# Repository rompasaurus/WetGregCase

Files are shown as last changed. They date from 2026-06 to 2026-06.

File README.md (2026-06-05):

# WetGregCase

A parametric, two-piece enclosure for the
[Dilder](https://github.com/rompasaurus) **Full PCB Rev 1**, generated by a
FreeCAD **PartDesign** macro.

> **Parametric, like `dilder_rev2_mk2`.** Every part is a PartDesign **Body**
> (Pad → Fillet → Thickness shell → pockets/pads) driven by a **`Parameters`
> spreadsheet**. Edit a cell and press **Ctrl+Shift+R**, or add/adjust fillets
> right on the feature tree in the GUI. All parts are single, watertight solids
> (clean B-rep — they slice without non-manifold errors).

- **Backplate** (Pico side) — the **board carrier**: wraps the board edge, the PCB
  **rests on top of a shelf** at its lower edge, with a **closed back panel** that
  closes off the +Z side (raised to clear the Pico).
- **Front cover** (screen side) — the screen lid below, built as a **constant-wall
  curved shell** so the aggressively curved front edge has no undercut gap. The
  screen sits recessed behind the front face (no clipping); the window is sized
  **inside the 4 M2 screw holes** so the frame fully covers them and the right-side
  8-pin connector. A round **5 mm boss** around the joystick hole leaves room for
  the solar-panel connector. The −X side is extended to wrap the screen edge.
- **Thumbpiece** — snap cap over the 5-way joystick (rev2-mk2 style).

The macro **imports the real KiCad STEP assembly**, aligned to the case — with the
unpopulated header pins **stripped** and the screen **shifted to meet the front
face** — so the fit is checked against actual geometry.

## Key facts

| | |
|---|---|
| Board | 97.8 × 42.0 × 1.6 mm, R5 corners |
| Screen face | meets screen top at Z = −11.4 |
| Backplate height | = USB-C connector (Z = +4.9) |
| Outer footprint | 105.4 × 46.6 mm (both plates, flush; −X extended for screen) |
| Overall height | **19.0 mm** (wall-thick shelled back clears the Pico) |
| Front curve | r = 6 mm — front **and** back edges (both shelled) |
| Closure | flush lap joint (tongue + relief) + PCB shelf + closed back |
| Controls | side USB-C opening · −Y power-switch slot · joystick thumbpiece |

## Layout

```
WetGregCase/
├─ freecad/
│  ├─ wetgreg_case.FCMacro   # parametric generator (edit PARAMS, re-run)
│  └─ WetGregCase.FCStd      # generated assembly
├─ exports/
│  ├─ WetGregCase_FrontCover.step
│  ├─ WetGregCase_BackPlate.step
│  └─ WetGregCase_Thumbpiece.step
├─ MODEL-SPEC.md             # full design spec, dimensions, open items
└─ README.md
```

## Run it

```bash
cd freecad && freecadcmd wetgreg_case.FCMacro   # headless regenerate
# or open the macro in the FreeCAD GUI and Execute
```

Then in the GUI: edit the **Parameters** spreadsheet and **Ctrl+Shift+R** to
recompute, or expand a Body in the tree to tweak any Pad/Fillet/Pocket. To add a
new fillet, select an edge and use PartDesign → Fillet.

> `freecad/wetgreg_case_partmode_backup.FCMacro` is the older non-parametric
> Part-workbench version, kept only as a reference.

See **[MODEL-SPEC.md](MODEL-SPEC.md)** for full dimensions and open items.

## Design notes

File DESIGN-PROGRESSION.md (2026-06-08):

# WetGregCase — Design Progression (manual FreeCAD walkthrough)

How to recreate this enclosure by hand in FreeCAD, step by step. The macro
(`freecad/wetgreg_case.FCMacro`) automates all of this from the `Parameters`
spreadsheet, but the steps below are what it does, in order.

**Coordinate frame (local):** `local = (KiCad_X − 46.70, KiCad_StepY + 88.0, Z)`
so the board sits at X 0..97.8, Y 0..42.012, with **Z = 0 at the PCB bottom**
face. +Z is the Pico/USB side (back), −Z is the screen/joystick side (front).

The case is a **clamshell**: a deep **front lid** (screen, Z −12.4 → 0) and a
deep **back cover** (Pico/USB, Z 0 → 8.5) that clips onto it.

---

## 0. New document
1. `File → New`. Save as `WetGregCase.FCStd`.

## 1. Import & align the Dilder PCB assembly (reference)
1. `File → Import` → `Dilder-PCB/Case Design/Dilder_PCB_FullAssembly.step`.
2. Select the imported part → **Edit → Placement** → Position `(−46.70, +88.0, 0)`.
   This lands the KiCad board into the local frame (board bottom at Z=0).
3. **Strip the unpopulated header pins:** delete the tall solid at the +Y edge
   (local X 8.4..28.7, Y 37..39.5, reaching Z +10.1) — those are empty holes.
4. **Keep the screen at its real STEP position (reality):** the imported screen's
   front face is at z=-8.64, which is ~1.36 mm behind the window-frame inner face
   (-10.0) — a genuine air gap, not a clip. `screen_cal`=0 leaves it there (the old
   build shoved it -1.36 mm onto the front floor, which made it clip the frame).
5. Keep this assembly visible, semi-transparent — it's the fit reference only.

## 2. Parameters spreadsheet
1. `Spreadsheet workbench → New sheet`, name it **`Parameters`**.
2. Add one row per dimension and **set an alias** on the value cell. Key ones:
   `board_w=96.8`, `board_h=42.012`, `wall=2.4`, `clear=0.3`, `ext_xmin=1.2`,
   `corner_r=7.7`, `screen_top=12.4`, `front_curve=6.0`, `back_above=8.5`,
   `back_curve=6.0`, `ledge_in=2.0`, `ledge_depth=10.0`, `lap=3.0`, `lap_fit=0.2`,
   `bead_proj=0.8`, `bead_h=1.2`, `snap_w=6.0`, `win_x0=11.6/x1=63.6/y0=7.1/y1=35.1`,
   `usb_*`, `sw_*`, `joy_*`, `thumb_*`, `bat_*`.
3. Drive every dimension below from these aliases (`Parameters.alias`) so editing
   a cell + **Ctrl+Shift+R** updates the model.

> Outer footprint corners (used below): X `−(ext+clear+wall)` .. `board_w+clear+wall`,
> Y `−(clear+wall)` .. `board_h+clear+wall`. Inner cavity = board + clear.

---

## 3. Front plate (screen lid) — PartDesign Body "FrontCover"
1. **New Body.** Sketch a rectangle on the XY plane at **Z = −12.4** covering the
   outer footprint (≈ 103.6 × 46.6). **Pad** it up to **Z = 0** (length `screen_top` = 12.4).
2. **Fillet** the 4 vertical edges → **7.7 mm** (rounded corners).
3. **Fillet** the front (−Z, bottom) perimeter edge → **6.0 mm** (the aggressive
   "looks-thin" curve).
4. **Thickness** (shell): select the open **+Z (top) face**, value **2.4 mm**,
   reversed/inward → a constant-wall curved shell, open at the top. *(Shelling
   after the fillet is what avoids the undercut gap the curve would otherwise make.)*
5. **PCB rib / ledge:** sketch a rounded **frame** (outer = wall inner; inner =
   2 mm further in, `ledge_in`) and **Pad it down** from Z=0 to the **front floor**
   (`ledge_depth` = `screen_top − wall` = 10.0). This is the lip the PCB rests on at
   Z=0, baked into the walls as a structural rib. Because the front wall curves
   inward below ≈−5.4, the straight rib outer ends up **inside** the curved wall,
   so the rib **merges with the curve** (no gap, no overhang, no poke-through) and
   meets the front face. Then Pocket a **screen-clearance box** (screen footprint
   +0.3, Z from the front floor up to `screen_back` (just past the real screen
   back) so the rib clears the screen on the −X edge.
6. **Screen window:** Pocket a rounded rectangle through the front frame, sized
   **inside the 4 M2 screw holes** so the frame covers them: X 11.6..63.6,
   Y 7.1..35.1 (1 mm shy of the screen PCB; X tucks the right-side 8-pin connector).
7. **Joystick boss:** add a **Ø20 cylinder**, **5 mm** tall, at (81.55, 21.30)
   from the front face inward — room for the solar-panel connector + thumbpiece.
8. **Battery / cable gap:** Pocket a blind notch at CN1 (X 41.5, −Y side) from the
   inside for routing battery cables. Its floor stops at **`bat_floor` (2.4 mm)
   above the front face** — i.e. just above the front floor — so the **front skin
   stays fully solid and printable** (no cut-through; the front is curved here, so
   the floor must clear the whole 2.4 mm front wall, not a thin slice). Start at the
   wall inner — **do not** cut the outer wall, and keep it below the window (Y < 7).
9. **Drill notches:** Pocket the rib away around the 2 mount holes closest to the
   Y axis (X 2.4, Y 9.0 and 33.4).
10. **Clip tongue + snap beads:** Pad a rounded frame ring up from Z=0 by
    `lap−lap_fit` (lap = 3 mm) at the inner wall, 0.2 mm clearance all round. Then
    add **discrete snap beads** (boxes) on the tongue's outer face — 2 per long
    wall + 1 on −X + **2 on +X flanking the USB-C port** (**7 total**) — each with a
    top lead-in chamfer. The bead projects
    `bead_proj` = 0.8 mm past the relief wall, so the thin tongue flexes ~0.6 mm and
    **clicks firmly** into the backplate recesses. The tongue is **continuous** all
    the way around — no relief cuts at the USB-C or switch — so the bead runs
    unbroken there for a stronger clasp. All inside the lap → **no added case
    thickness**. *(The 2.4 mm wall, +0.4 over the original 2.0, is what leaves a
    ~0.5 mm solid skin behind the deeper recess so the back wall isn't cut through.)*
11. **Joystick hole:** Pocket a **Ø12** cylinder through everything at (81.55, 21.30).

> **Sizing the +X length:** the case length is driven entirely by `board_w`
> (`OX1 = board_w + clear + wall`). To shorten the case, *reduce `board_w`* — never
> slab-cut the +X end, which would flat-chop the corner fillet and edge curve.
> `board_w` = 96.8 (1 mm under the KiCad nominal, matching the real board).

## 4. Back cover — PartDesign Body "BackPlate"
1. **New Body.** Rectangle on XY at **Z = 0** (outer footprint). **Pad** up to
   **Z = 8.5** (`back_above`).
2. **Fillet** vertical edges → 7.7 mm.
3. **Fillet** the **+Z (top) back edge** → 6.0 mm (same curve as the front).
4. **Thickness** (shell): open the **−Z (bottom) face**, 2.4 mm inward → curved
   closed back, walls, open toward the front. Houses the USB-C + Pico.
5. **Lap relief + snap recesses:** Pocket a rounded frame (inner wall, over the
   `lap` band from Z=0 up) to receive the front tongue. Then Pocket a **recess at
   each snap bead** in the relief wall — the relief wall stays solid between
   recesses, so the beads must flex past it and snap home.
6. **USB-C opening:** Pocket through the +X wall, Y 16.2..25.8, Z 0..5.2, with
   1 mm rounded corners.
7. **Power-switch slot:** Pocket through the −Y wall, X 47.5..53.5, Z 1.0..3.3.

## 5. Thumbpiece — PartDesign Body "Thumbpiece"
1. **New Body.** Additive **cylinder** Ø11 × 4.5 at (81.55, 21.30), front face.
2. **Subtractive sphere** R12 on the outer face → concave thumb dish.
3. **Subtractive box** 3.3 × 3.3 × 3.5 from the inner face → socket for the
   K1-1506SN-01 actuator.

## 6. Check
- Each Body should be a **single, closed (watertight) solid**.
- Front↔Back **interference = 0** when assembled (clip seats with 0.2 mm slip).
- Overall size ≈ **103.4 × 47.4 × 20.9 mm** (board_w 96.8; walls +0.4; curves intact).

---

## Why each measure
| Measure | Reason |
|---|---|
| translate (−46.70, +88, 0) | maps the KiCad STEP into the local frame |
| front-cover depth `screen_top` = 12.4 | screen standoff + 1 mm; screen rests just behind the window |
| shell (Thickness) after the fillet | curved wall with no undercut gap |
| ledge rib Z 0 → −10.0 (front floor) | PCB rests at Z=0; rib runs to the front floor, meshes with the curve, clears the screen |
| window inside the screw holes | frame fully covers the M2 holes + 8-pin connector |
| back cover Z 0 → 8.5 | clears the Pico (5.26) **and its micro-USB** under a wall-thick curved back |
| discrete snap beads inside the lap (0.55 mm interference) | front/back click together; no external features, no added thickness |
| ext_xmin = 1.2 | front = PCB + walls (not over-wide); clears the screen edge |

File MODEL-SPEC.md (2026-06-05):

# WetGregCase — Model Specification

A two-piece **slim** 3D-printed enclosure for the **Dilder Full PCB Rev 1**,
generated by `freecad/wetgreg_case.FCMacro`. The macro imports the real KiCad
STEP assembly (aligned, unpopulated header pins stripped, screen shifted to meet
the front face) and adds a snap-on joystick thumbpiece.

> Status: **v9 — parametric PartDesign rewrite.** Every part is a PartDesign Body
> (Pad → Fillet → Thickness shell → pockets/pads) driven by the **`Parameters`
> spreadsheet** (edit a cell + Ctrl+Shift+R, or add/adjust fillets on the feature
> tree). Both halves are curved constant-wall shells; all parts are single,
> watertight solids that slice cleanly. ~19.0 mm thick.
>
> Architecture (clamshell, seam at the PCB plane Z=0):
> * **FrontCover** = the screen lid (Z −11.4 → 0). Curved-shell front, screen
>   window, joystick boss/hole, battery-connector gap, and a **lip** the dilder
>   PCB rests on. All frame features are **rounded** (corners follow the wall
>   fillet — no corner overhang).
> * **BackPlate** = the deep cover (Z 0 → 7.5) that **clips onto the front lid**
>   and houses the **USB-C + Pico**; constant-wall curved shell with the **same
>   r6 edge curve as the front**, USB-C + switch openings.
> * Clip = flush lap (tongue on the front, relief in the back) + snap bead/groove.
>
> Feature tree: **FrontCover** = Pad → Fillet_Corners → Fillet_Front → Shell →
> Pad_Ledge → Cut_Window → Boss_Joy → BatteryGap → DrillNotches → Tongue + Bead →
> Cut_Joy. **BackPlate** = Pad → Fillet_Corners → Fillet_Back → Shell → Relief →
> Groove → USB → Switch. **Thumbpiece** = Disc → Dish → Socket.
>
> Closure: flush lap (tongue + relief, 0.2 mm slip) with a **snap bead + groove**
> running along the lap (bead on the front-cover tongue clicks into a groove in
> the backplate relief). The dilder PCB rests on a **thin side lip at Z=0** (USB
> cutout starts at Z=0 to match); the lip has a USB notch.

---

## 1. Orientation & coordinate frame

`local = (KiCad_X − 46.70, KiCad_StepY + 88.0, Z)` — **Z = 0 is the PCB bottom
face**; board X 0..97.8, Y 0..42.012.

| Side | Z | Contents | Case part |
|---|---|---|---|
| **Front** | **−Z** | WeAct screen + 5-way joystick | **Front cover** (screen lid) |
| **Back** | **+Z** | Pico W, USB-C, power switch | **Backplate** (board carrier) |

---

## 2. Real component geometry (from the STEP, local mm)

| Component | Side | X | Y | Z |
|---|---|---|---|---|
| WeAct screen | −Z | −0.4 … 71.6 | 6.1 … 36.1 | front shifted to **−11.4** |
| 5-way joystick | −Z | 75.7 … 87.4 | 16.2 … 26.4 | actuator to −10.1 |
| 8-pin connector | +Y | 8.4 … 28.7 | 37.0 … 39.5 | window stops 1 mm before (Y=36) |
| Pico W | +Z | 5.3 … 57.6 | 10.7 … 31.7 | 1.56 … 5.26 |
| USB-C | +Z | +X edge | 16.4 … 25.6 | 0.67 … **4.89** |
| Power switch | +Z | 47.2 … 53.9 | −Y edge | 1.06 … 3.07 |
| Header pins (empty) | +Z | 8.4 … 28.7 | 37 … 39.5 | **stripped** |

---

## 3. Architecture

```
                       aggressive front curve (r6)
  Z=-11.40  ╰─╮  screen window (stops before 8-pin) + joystick hole ╭─╯  = screen top
            FRONT COVER (screen lid) · 5 mm boss by joystick (solar conn.)
            −X side extended to wrap the screen edge + screw holes
  Z= -1.50 ═╪═════════════ FLUSH lap joint (shelf plane) ═══════════╪══  sides flush
  Z=  0.00       PCB rests ON TOP of the shelf  ───────────────────
            BACKPLATE (board carrier) — wraps board edge, open centre
            USB-C (+X) · switch slot (−Y)
  Z= +4.90  ╰──────────────────────────────────────────────────────╯  = USB-C height
```

### Backplate (board carrier, +Z)
- Wraps the board edge; only as tall as the USB-C connector (outer Z = +4.9).
- **Shelf under the board** (at the lower edge): the PCB **rests on top of it**.
  The shelf bridges the −X extension so it grips the board on all four sides.
- **Open centre** so it never touches a component (Pico exposed/accessible).
- **USB-C opening** (+X) · **power-switch slot** (−Y).

### Front cover (screen lid, −Z)
- Outer face **meets the screen top at Z = −11.4**; thin 1.2 mm front frame.
- **Screen window** inset by a 2.5 mm bezel so the frame **wraps the screen and
  covers the corner screw holes**; the +Y edge **stops 1 mm before the 8-pin
  connector** (pins hidden under the plate).
- **−X extended by 3 mm** so the wall wraps the screen's overhanging edge instead
  of clipping it.
- **5 mm-thick boss** around the joystick → room for the solar-panel connector and
  the thumbpiece.
- **Aggressive curve** (r = 6 mm) on the front outer edge.
- **Joystick hole** (Ø12) + flush lap tongue + snap nibs.

### Thumbpiece
- Snap cap over the K1-1506SN-01 actuator (rev2-mk2 style): Ø11 disc, dish,
  3.3 mm square socket. On the front.

---

## 4. Key dimensions

| Dimension | Value |
|---|---|
| Outer footprint (both plates, flush) | **105.40 × 46.61 mm** (−X extended 3 mm) |
| Overall height | **16.30 mm** (Z −11.40 → +4.90) |
| Screen face / backplate top | Z = −11.40 / +4.90 |
| Flush lap / PCB shelf top | Z = −1.50 / 0.00 |
| Wall / front frame | 2.0 / 1.2 mm |
| Joystick boss | 5.0 mm thick |
| Front curve | r = 6.0 mm |
| Bezel (screw-hole coverage) | 2.5 mm |
| PCB shelf | 1.6 mm grip, 1.5 mm thick |

All three printed parts verified as **valid, closed (watertight) solids**.
Imported assembly: 286 solids (1 header stripped, 99 screen sub-solids shifted).

---

## 5. Open items / confirm during validation

1. **Screen screw holes / bezel.** The 2.5 mm bezel covers holes within ~2.5 mm of
   the screen edge. If holes sit further in (or you want the exact active-glass
   window), give me the hole/active-area coordinates and I'll tighten it.
2. **−X extension (3 mm).** Sized to wrap the 0.4 mm screen overhang plus a full
   wall; adjust `ext_xmin` if you want it tighter/looser.
3. **5 mm joystick boss** spans X 71–93, Y 11–31. Tell me the solar-connector
   footprint if it needs a specific pocket rather than just thickness.
4. **Pico (5.26) vs backplate top (4.9):** Pico sits ~0.36 mm proud of the open
   backplate centre (exposed, no collision).
5. **Bezel overlaps the screen front** in the model (intended — the frame covers
   the border). The real screen sits flush behind it.
6. No bolt bosses (closure is snap + shelf). `import_assembly=False` for a
   case-only run; `explode_z` for an exploded view.

---

## 6. How to run

```bash
cd freecad && freecadcmd wetgreg_case.FCMacro     # headless regenerate
# or open the macro in the FreeCAD GUI → Execute
```

Outputs `freecad/WetGregCase.FCStd` and STEP files for the front cover, backplate
and thumbpiece in `exports/`.

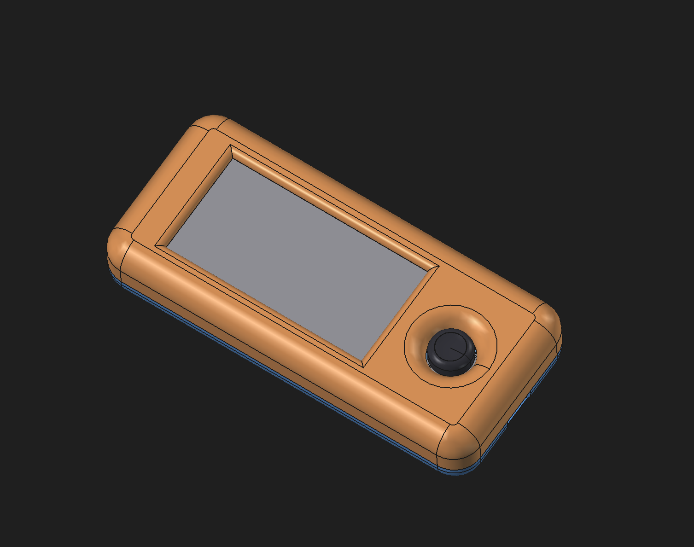
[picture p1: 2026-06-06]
WetGregCase FIrst Pass.png

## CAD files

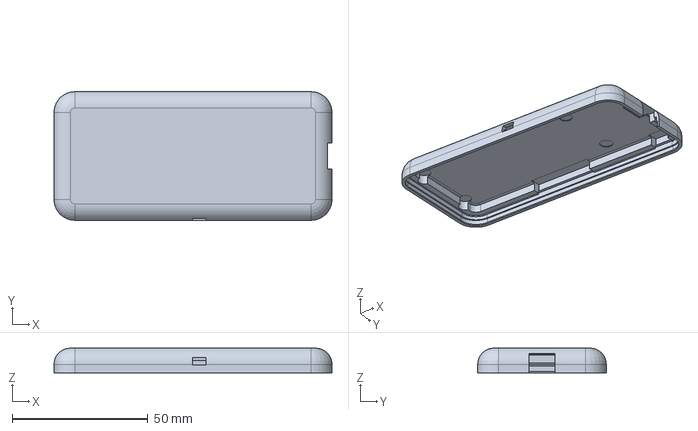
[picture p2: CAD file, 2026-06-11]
exports/WetGregCase_BackPlate.step
102.5 x 47.4 x 9.10 mm

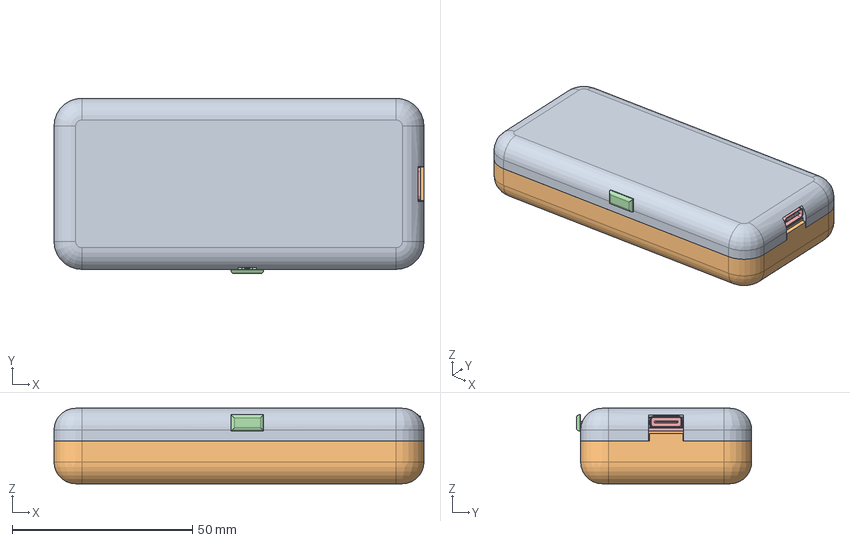
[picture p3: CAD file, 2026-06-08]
freecad/WetGregCase.FCStd
102.5 x 48.6 x 20.9 mm
BackPlate
FrontCover
Thumbpiece
SwitchSlider
Dilder_Assembly

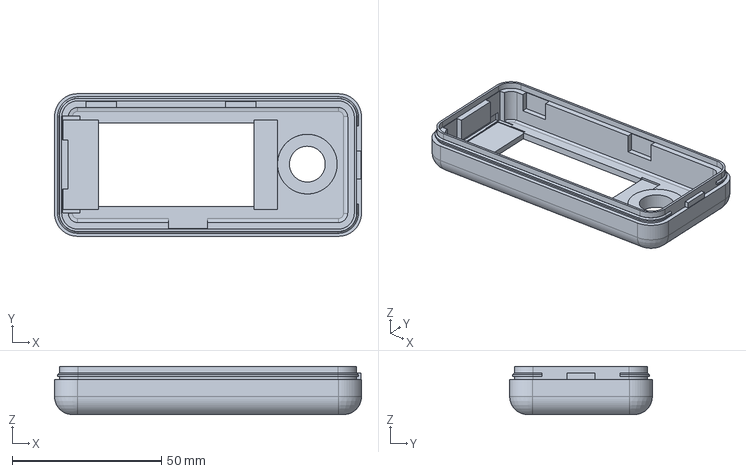
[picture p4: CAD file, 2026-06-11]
exports/WetGregCase_FrontCover.step
102.9 x 47.8 x 16.1 mm

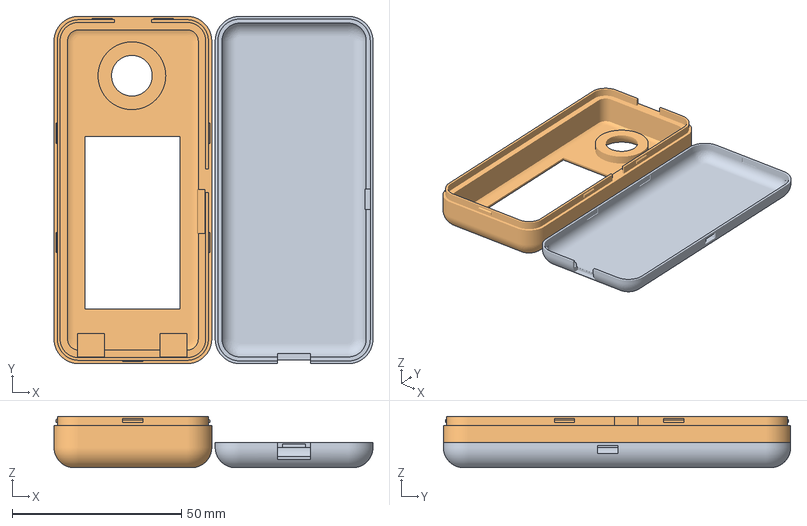
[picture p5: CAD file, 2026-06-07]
freecad/WetGregCase-almost htere2 front plated perfect need thiccer back.3mf
94.2 x 102.6 x 15.2 mm

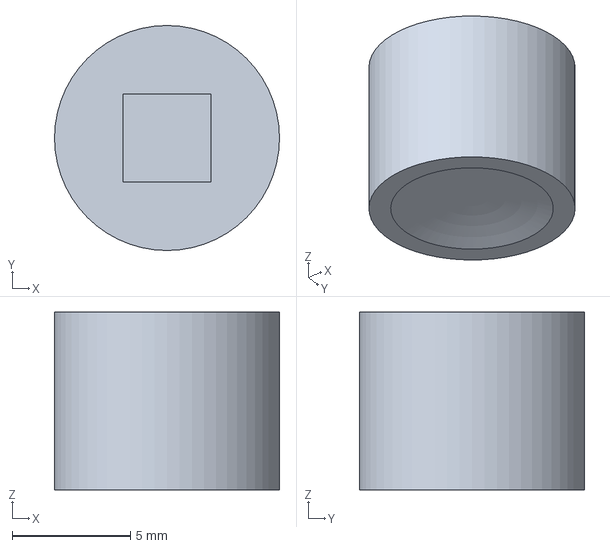
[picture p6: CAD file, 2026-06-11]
exports/WetGregCase_Thumbpiece.step
9.50 x 9.50 x 7.50 mm

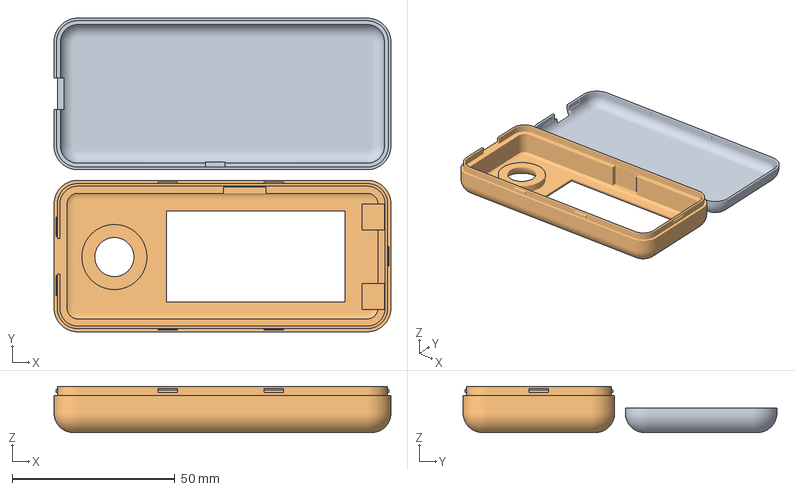
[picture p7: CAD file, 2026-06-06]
freecad/WetGregCase-almost htere.3mf
103.6 x 96.5 x 14.2 mm

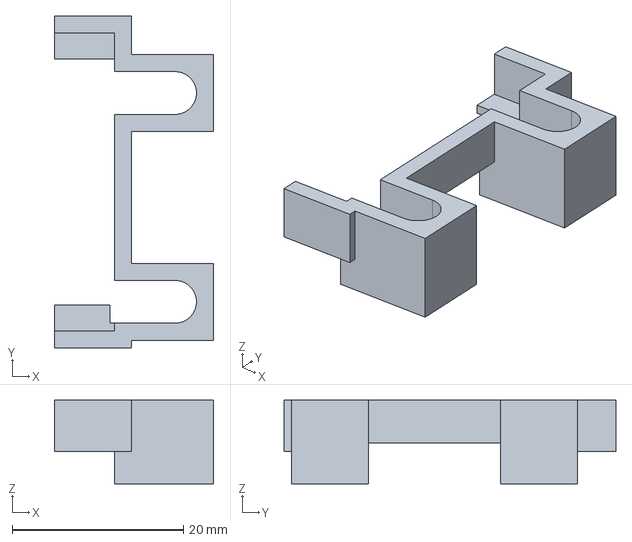
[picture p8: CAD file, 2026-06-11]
exports/WetGregCase_BatteryClipR.step
18.6 x 38.8 x 9.80 mm

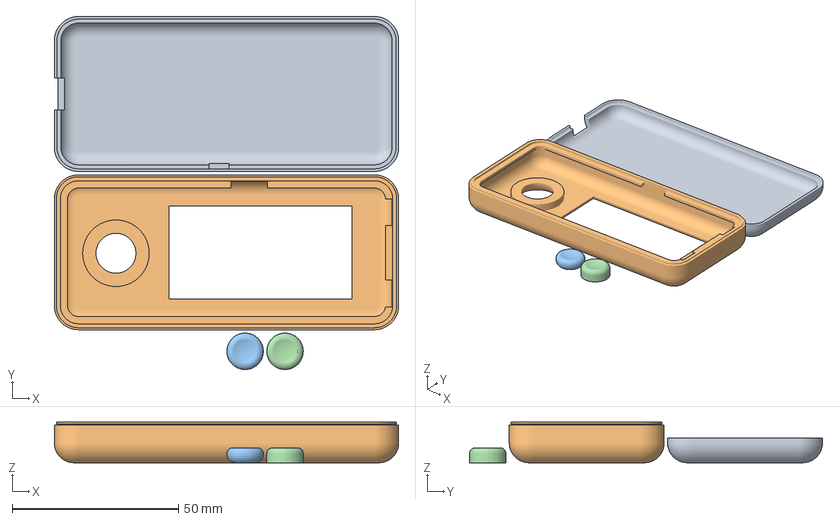
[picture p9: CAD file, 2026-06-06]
freecad/WetGregCase-Firs Attemptr.3mf
103.6 x 106.2 x 12.2 mm

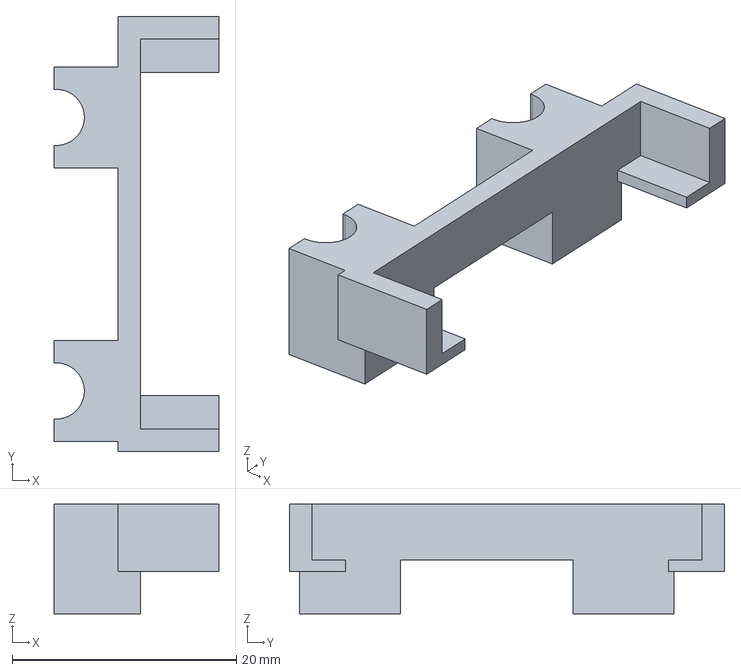
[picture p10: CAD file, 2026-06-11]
exports/WetGregCase_BatteryClipL.step
14.7 x 38.8 x 9.80 mm

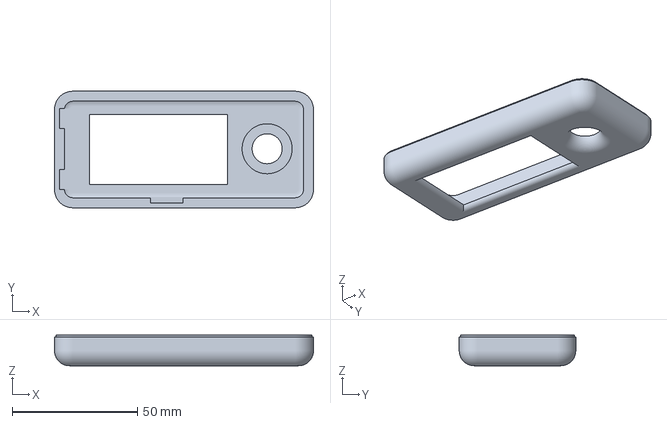
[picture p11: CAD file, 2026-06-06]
freecad/WetGregCase-FrontCoverPropper SHelf.3mf
103.6 x 46.6 x 12.2 mm

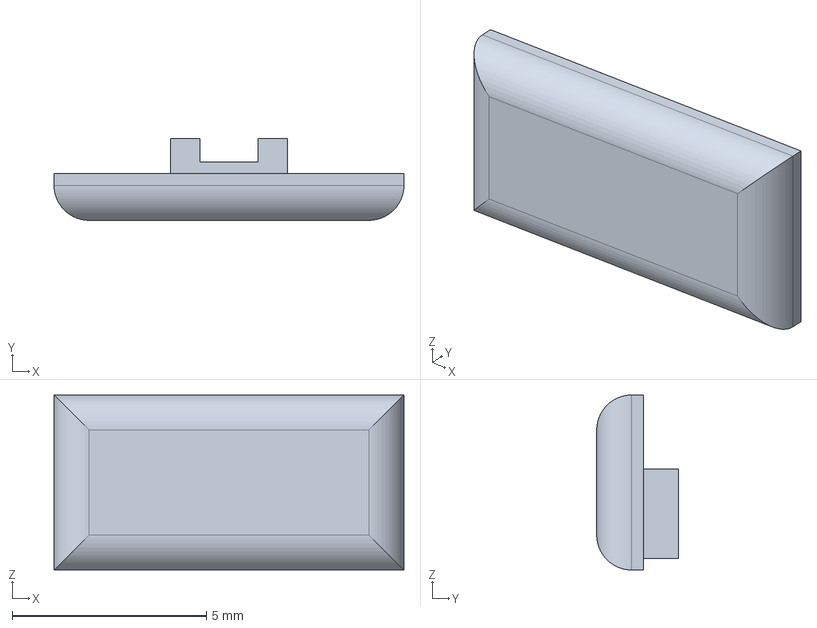
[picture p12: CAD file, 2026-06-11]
exports/WetGregCase_SwitchSlider.step
9.00 x 2.10 x 4.50 mm

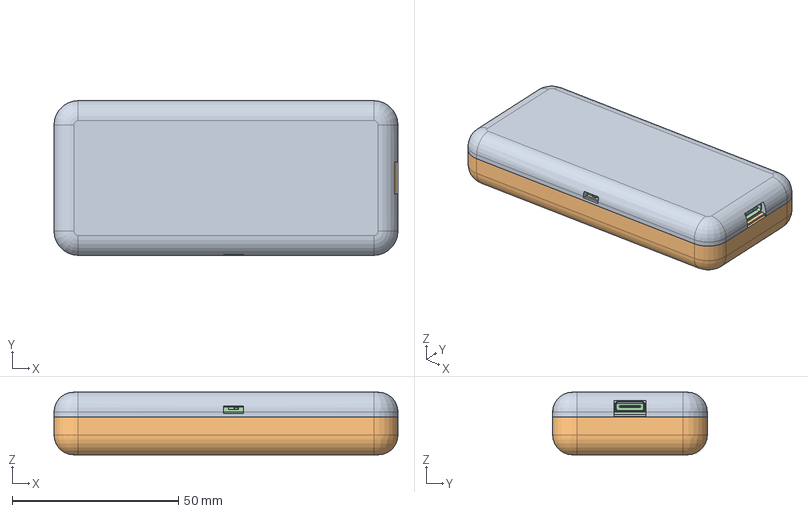
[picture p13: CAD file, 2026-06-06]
freecad/WetGregCase SOlid FIrst Pass.FCStd
103.6 x 46.6 x 18.9 mm
BackPlate
FrontCover
Thumbpiece
Dilder_Assembly

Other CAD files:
freecad/WetGregCase-BackPlate.3mf
freecad/WetGregCase-BatteryClipL.3mf
freecad/WetGregCase-BatteryClipR.3mf
freecad/WetGregCase-FrontCover.3mf
freecad/WetGregCase-SwitchSlider.3mf
freecad/WetGregCase-Thumbpiece.3mf

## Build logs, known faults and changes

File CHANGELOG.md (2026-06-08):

# WetGregCase — Revision History

Design revisions of the parametric FreeCAD enclosure, newest at the bottom.
Every part is driven by the `Parameters` spreadsheet in `freecad/wetgreg_case.FCMacro`.

| Rev | Change |
|---|---|
| init | Two-piece snap-fit case scaffold + GitHub repo |
| v1 | Flush lap joint, real KiCad STEP assembly import, joystick thumbpiece, switch slot |
| v2 | Slim case — screen+joystick on the front, thin USB-C-height backplate, curved front |
| v3 | Backplate as board carrier, screen wrap, joystick boss, window before pins |
| v4 | Closed back panel, curved shell (no undercut gap), recessed screen, round joystick boss |
| v5 | Screen window sized inside the 4 screw holes (fully covered) + back-edge curve |
| v6 | Screen window extended in Y to 1 mm shy of the screen-PCB edges |
| v7 | Narrow switch slot to actuator travel; tighten the USB-C opening |
| v8 | Slot the PCB shelf under the USB-C connector |
| **v9** | **Parametric PartDesign rewrite with a `Parameters` spreadsheet (like dilder mk2)** — clean B-rep, slices cleanly |
| v10 | Thin PCB side lip + snap bead/groove closure; narrow window −X edge |
| v11 | Fix mate z-fighting — all-around clearance on the lap tongue |
| v12 | Front plate becomes the tray (PCB on internal ledge); backplate = clip-on cap |
| v13 | Notch the front ledge around the 2 mount holes nearest the Y axis |
| v14 | Rounded frame features (no corner overhang); patch battery wall hole; narrower front |
| v15 | Clamshell flip — front = screen lid (lip), backplate = deep curved cover (USB+Pico) |
| v16 | Pad the PCB ledge down into a structural side rib |
| v17 | Extend battery gap into the curved front-bottom for cable routing |
| v18 | Keep the front floor solid under the battery gap (no cut-through) |
| v19 | Fix PCB rib overhang at the curve (straight-wall depth + 45° chamfer) |
| v20 | Rib meets the front face and meshes with the curve (no chamfer) + screen clearance |
| v21 | Raise front-cover depth +4 mm (PCB shelf 11.4 → 15.4) |
| v22 | Real snap-fit closure — discrete snap beads inside the lap (no added thickness) |
| v23 | Move +X snaps to flank the USB-C port (keep the port hole intact) |
| v24 | Fix snap recess depth (don't cut the back curve) + −X snap missing the extended wall |
| v25 | USB-C clearance gap in the front +X tongue (connector settles in) |
| v26 | Reduce front-cover depth back to the screen standoff (screen rests at the window) |
| v27 | +1 mm front-cover thickness; shave 2 mm off each end of the window's long edges (−4 mm); auto-export 3MF print meshes |
| v28 | Trim the +X end 1 mm past the USB-C (drops the +X snaps, keeps 5); cut a power-switch clearance gap in the front −Y tongue |
| v29 | **Undo the +X slab trim** (it flat-chopped the corner curve). Shorten by reducing `board_w` 97.8 → 96.8 so the whole case regenerates 1 mm shorter with all fillets/curves intact; restore the 2 +X snaps flanking the USB-C |
| v30 | Deepen the backplate 1 mm (`back_above` 7.5 → 8.5) so it closes flush over the Pico's micro-USB |
| v31 | Stronger clasp: drop the front-tongue relief cuts at the USB-C & switch (`Cut_FC_USB`/`Cut_FC_Switch`) so the bead runs unbroken; +0.4 mm bead projection (0.4 → 0.8); +0.4 mm walls all around (`wall` 2.0 → 2.4, `corner_r` → 7.7) to keep a solid recess skin and mate smoothly; +0.2 mm USB-C opening depth (`usb_z1` 5.0 → 5.2) |
| v32 | Extend the window's Y-axis edge 1 mm toward the Y axis (`win_x0` 12.6 → 11.6) |
| v33 | Extend the USB-C opening depth another 0.4 mm (`usb_z1` 5.2 → 5.6) |
| v34 | Extend the USB-C opening depth another 0.4 mm (`usb_z1` 5.6 → 6.0; ~at the inner ceiling 6.1) |
| v35 | Carve the USB-C slot up into the curved top cap (`usb_z1` 6.0 → 7.5) so the connector clears the curvature; ~1 mm cap roof remains, curve intact off the USB window |
| v36 | Run the USB-C slot clean through the curved cap to the back face (`usb_z1` 7.5 → 9.0 ≥ cap top) — open-topped notch, no curve overhang; cap intact outside the USB window |
| v37 | Start the USB-C cut `back_curve` (6 mm) further inboard so it also removes the top cap's inward lean over the USB window (the rounded edge curves toward −X near the top); cap intact off the USB window |
| v38 | Pull the USB-C cut back from the base (`usb_z1` 9.0 → 7.0): no longer cuts through the back face, leaves a ~1.5 mm solid cap roof (still clears the connector ~4.9) |
| v39 | Front-cover outer lip at the USB notch (`Lip_FC_USB`, `usb_lip_h`=2.1): fills the lower part of the backplate's USB cutout flush with the outer surface, covering the bead/seam; +0.4 mm back-cover depth (`back_above` 8.5 → 8.9) so the Pico clears the shell |
| v40 | Raise the power-switch slot 1 mm (`sw_z0` 1.0 → 2.0, `sw_z1` 3.3 → 4.3); confirmed it cuts clean through the −Y wall |
| v41 | Reduce the USB-C cutout depth 0.6 mm (`usb_z1` 7.0 → 6.4); thicker ~2.5 mm cap roof, still clears the connector |
| v55 | Back cover +1 mm (`back_above` 8.1 → 9.1, overall 20.93). Cut the +Y (top) shelf away at the middle for the accelerometer so the board lays flat, and gap the shelf at the +X/−Y corner (by the USB-C) for the LEDs (both start at the wall inner — no side holes) |
| v54 | Fix the back shelf's switch/battery gap cutting a **hole in the −Y side wall** (the gap started outside the wall) — gaps now start at the wall inner and only remove the inner shelf. Reduce the back cover 2 mm (`back_above` 10.1 → 8.1): the Pico is modelled as a solid 3.7 mm block but the real Pico is mostly thin PCB, so the dead space above it is removed (overall 21.93 → 19.93) |
| v53 | (a) Front: carve 1 mm more into the inner −X wall at the screen edge (`scr_carve_in`; leaves 1.2 mm wall, no pop-through). (b) Bead +1 mm taller (`bead_h` 1.2 → 2.2, centred so the USB-C still clears the tongue; snap still seats). (c) **Back perimeter support shelf** (`Pad_BP_Shelf`) clamping the board's outer edge between the front rib and the shelf, with M2 standoff notches, USB-C/switch/battery gaps, and an open centre clearing the Pico/accel/LEDs/caps |
| v52 | Trim the back cover to its minimum closed depth (`back_above` 10.2 → 10.1). The Pico (7.36) is the tallest +Z part — 0.37 mm above the USB-C (6.99) — so the closed back is set by the Pico, not the USB-C; ceiling now clears the Pico by 0.35 mm |
| v51 | Deepen the front cover for the real screen stack: measured **13 mm** top-of-screen to PCB-backside (STEP model had it ~2.9 mm too close). `screen_top` 8.94 → 11.83, `screen_cal` 0 → −2.89 (shift screen out to reality), `ledge_depth` → 11.53. Screen now sits just behind the window, no poke; stack verified 13.00 mm. Overall 19.14 → 22.03 |
| v50 | Fix the M2 drill-notch z: it used the pre-raise rib bottom (`-ld`), which after the board raise sliced through the front wall → holes at the screen top. Now tracks the raised rib (`pcb_rest_z - ld`); front face solid again |
| v49 | Fix two v48 regressions: board now sits **exactly flush** with the bead top (`board_rest_z` 2.13 → 2.10 = bead top); and **restore the USB-C + Pico** to the reference assembly — the header-strip threshold (ZMax>6) now rises with `board_rest_z`, so the raised Pico/USB are no longer deleted as if they were header pins |
| v48 | **Board now rests ON the bead** (`board_rest_z` 0.63 → 2.13): the board bottom sits ~at the bead top, lifting the USB-C base (2.80) clear of the tongue top (2.8). So the **USB tongue relief is removed entirely** (`Cut_FC_USB` gone) — the bead/tongue fully connect under the connector — and the **lip meets the bead top** (`usb_lip_h` → 2.10). Back deepened (`back_above` → 10.2) so the now-higher Pico clears; front thinner (`screen_top` → 8.91); `usb_z1` → 7.2 for the raised connector. Overall 19.31 → 19.11 |
| v47 | **Raise the board so the PCB top is flush with the bead top** (new `board_rest_z`=0.63; bead restored to the lap centre). Lifts the USB-C/switch into the backplate (accessible) and lets the front USB lip grow (`usb_lip_h` 0.67 → 1.3). Front thinner (`screen_top` → 10.41; overall 19.94 → 19.31); Pico still clears (back unchanged). Slider tab thinner + rounded (more flush to the side) and tracks the raised switch |
| v46 | **Slide-switch (MSK12C02) slider — v1.** Enlarge the −Y slot to a slider window (`sw_*`/`sld_*` params) exposing the actuator; add a printed `SwitchSlider` part (thumb tab + neck + knob grip pocket) that rides the slot. Valid solid, fits with clearance. Grip + full case-rail capture need the real knob width/travel/protrusion (assumed 1.2/1.5/0.6 mm) |
| v45 | Lower the snap bead so its top is flush with the PCB top (`bead_z` = board_t − bead_h; `board_t` 1.6 → 1.47 real). USB tongue relief kept minimal — raising the board to clear it would push the Pico into the back cover (thicker), which conflicts with the connector sitting below the PCB top |
| v44 | Bring the −X short side in 0.9 mm (`ext_xmin` 1.2 → 0.3) so the wall clears the screen overhang (−0.394) by 0.2 mm; keep the screen-clearance pocket from breaching the tightened wall. Restore the USB lip to meet the connector (`usb_lip_h` 0.5 → 0.67) |
| v43 | **Front cover 1.36 mm thinner** to match reality: real screen sits 8.64 mm from the board, so `screen_top` 12.4 → 11.04 (`ledge_depth` → 8.64). Window inner now meets the screen so the board seats on the shelf; overall height 21.3 → 19.94 |
| v42 | **Calibrate the reference assembly to reality.** Keep the screen at its authoritative STEP position (`screen_cal`=0; was shoved −1.36 mm onto the case front floor) → it now sits ~1.36 mm behind the window as in reality. Extend the rib's screen-clearance to the real screen back (`screen_back`). Fix the USB-C colliding with the front cover: lower the lip below the connector (`usb_lip_h` 2.1 → 0.5) and re-add a narrow tongue relief at the USB window (lip + flanking beads kept) |

## Current key dimensions (v55)

| | |
|---|---|
| Outer footprint | 102.5 × 47.4 mm (−X brought in to clear the screen +0.2) |
| Overall height | 20.93 mm |
| Front-cover depth | `screen_top` = 11.83 mm (real screen 8.64 − board_rest_z + wall) |
| Backplate depth | `back_above` = 9.1 mm (USB-C + Pico; clears micro-USB + Pico-to-shell) |
| Wall / curves | 2.4 mm walls · r7.7 corners · r6 front **and** back edge curves |
| Screen window | X 11.6–63.6, Y 7.1–35.1 (inside the screw holes; long edges shaved) |
| Closure | flush lap + discrete snap beads (2/long wall + 1 −X + 2 +X flanking the USB-C = 7), 0.8 mm projection, tongue continuous at the USB/switch |
| Controls | side USB-C opening · −Y switch slot · joystick boss + thumbpiece |

## Outputs (regenerated by the macro)
- `freecad/WetGregCase.FCStd` — full assembly + Parameters spreadsheet
- `exports/WetGregCase_{FrontCover,BackPlate,Thumbpiece}.step`
- `freecad/WetGregCase-{FrontCover,BackPlate,Thumbpiece,SwitchSlider}.3mf` — print-ready meshes
- `exports/WetGregCase_SwitchSlider.step`

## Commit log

2026-06-05 Initial WetGregCase: parametric 2-piece snap-fit case for Dilder PCB
    Two-piece enclosure generated by a FreeCAD macro:
    - Back plate tray with inward lip the PCB rests on
    - Front plate snaps around it, screen window for WeAct e-ink
    - 11.4mm screen clearance above PCB top, +2mm back allowance
    - Embeds full KiCad layout (screen, battery, joystick, Pico W, USB-C, switch)
    - Validated as watertight solids; STEP exports included
    [WetGregCase.FCStd, WetGregCase_BackPlate.step, WetGregCase_FrontPlate.step]
2026-06-05 v1: flush lap joint, real STEP assembly import, joystick thumbpiece, switch slot
    - Import the real Dilder_PCB_FullAssembly.step (287 solids) aligned to the
    case frame; replaces crude primitive component boxes
    - Fix Y-mirror: case now built in the true STEP frame (translate -46.70,+88,0),
    so the power switch lands on the correct (-Y) wall
    - Flush lap joint: both plates share one outer footprint (102.4x46.6) with an
    interlocking tongue/relief + 6 internal snap detents (sides flush, no overhang)
    - Add joystick thumbpiece (K1-1506SN-01, rev2-mk2 style) + Oe12 hole on back
    - Power-switch slot on -Y wall for external toggling
    - Back cavity 10.5mm to clear real back components (joystick/conne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
    [WetGregCase.FCStd, WetGregCase_BackPlate.step, WetGregCase_FrontPlate.step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]
2026-06-05 v2: slim case — screen+joystick front, thin USB-C-height backplate, curved front
    - Correct orientation: screen and joystick are on the SAME side (-Z); screen
    window + joystick hole/thumbpiece now both on the front cover
    - Front cover outer face meets the screen top (Z=-11.4); thin 1.2mm frame
    - Thin backplate on the Pico side, only as tall as the USB-C connector (Z=4.9),
    a perimeter frame with a small shelf the PCB rests on, open centre (won't
    touch components)
    - Aggressive curved front edge (r6) so the case reads thinner than it is
    - Import: strip unpopulated header pins, shift screen (99 solids) to meet face
    - Overall height 25.1 -> 16.3mm; all parts valid + watertight
    Co-Authored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
    [WetGregCase.FCStd, WetGregCase_BackPlate.step, WetGregCase_FrontCover.step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]
2026-06-05 v3: flip to board-carrier backplate, screen wrap, joystick boss, window-before-pins
    - Flip architecture per feedback: BACKPLATE is now the board carrier (wraps the
    board edge; PCB rests ON TOP of a shelf at its lower edge). FRONT COVER is the
    screen lid below. Lap mates on the correct edge.
    - Window now stops 1mm before the 8-pin connector (Y=36) so those pins are hidden
    under the front plate
    - Extend case -X by 3mm so the front wraps the screen's overhanging edge (was
    clipping through the wall); bezel 2.5mm to cover the screen's corner screw holes
    (shelf bridges the extension to keep gripping the board on all sides)
    - Add 5mm-thick boss by the joystick to leave room for the solar-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
    [WetGregCase.FCStd, WetGregCase_BackPlate.step, WetGregCase_FrontCover.step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]
2026-06-05 v4: closed back panel, curved shell (no gap), recessed screen, round joystick boss
    - Front cover now a constant-thickness curved SHELL (makeThickness): the r6
    front curve no longer undercuts the wall -> fixes the weird empty-space gap
    - Recess the screen behind the front inner face so the frame no longer clips
    the screen/screw holes (overlap 307 -> 0.9 mm^3)
    - Backplate closes off the +Z side with a closed back panel (raised to clear
    the Pico, 5.26mm); verified 4867mm^2 closed top
    - Joystick fill is now a round 5mm boss right around the hole, not a square block
    - All parts valid + watertight; height 16.3 -> 18.4mm (closed back)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
    [WetGregCase.FCStd, WetGregCase_BackPlate.step, WetGregCase_FrontCover.step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]
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2026-06-05 v7: narrow switch slot to actuator travel + tighten USB-C opening
    - Switch slot 9.7 -> 6.0mm (X 47.5..53.5), Z 0.4..3.5 -> 1.0..3.3: just enough
    for the slide actuator to move (switch body is 47.2..53.9)
    - USB-C opening tightened to hug the connector (Y 9.7mm vs body 9.1, Z 0.5..5.0
    vs body 0.67..4.89) with 1mm rounded corners for the port shape
    - All parts valid + watertight
    [WetGregCase.FCStd, WetGregCase_BackPlate.step, WetGregCase_FrontCover.step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]
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2026-06-05 v10: thin PCB side lip + snap bead/groove closure + narrow window -X edge
    - Replace the thick bottom shelf with a thin side LIP at Z=0 (board bottom rests
    on it); drop USB cutout bottom to Z=0 so the lip starts where the USB cutout
    ends (closest to origin); lip keeps a USB notch. PCB no longer shifted.
    - Add a snap BEAD on the front-cover tongue + matching GROOVE in the backplate
    relief -> clicks the two halves closed along the lap (seated overlap 0;
    interference only during insertion)
    - Bring the screen window -X edge in 5mm (win_x0 5.6 -> 10.6)
    - Verified: lip on side walls (open centre), PCB rests on it, all three parts
    single watertight solids; bead/groove/lip present in the fe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
    [WetGregCase.FCStd, WetGregCase_BackPlate.step, WetGregCase_FrontCover.step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]
2026-06-05 v11: fix mate z-fighting — give the lap tongue all-around clearance
    The 'weird planes clipping through the back' were coincident faces at the mate:
    the front-cover tongue shared planes with the backplate lip (both at O_IN) and
    the relief walls (overlapping in Z), so FreeCAD z-fought them when both parts
    were shown.
    - Inset the tongue inner by lap_fit and shorten it below the relief top, so it
    sits inside the relief with 0.2mm clearance on inner/outer/top (no shared
    planes). Snap bead still engages (interference only during insertion).
    - Verified: FC<->BP solid overlap 0; the only touching face is the outer seam
    (the intended flush closing contact). All parts single watertight solids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
    [WetGregCase.FCStd, WetGregCase_BackPlate.step, WetGregCase_FrontCover.step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]
2026-06-05 v12: front plate becomes the tray (PCB on internal ledge); backplate is a clip-on cap
    Per feedback: the dilder PCB now rests INSIDE the front plate.
    - Move the seam up above the Pico (Z=5.5) so the FRONT plate is the full tray
    holding the screen + PCB; the PCB rests on an internal LEDGE where the side
    walls come in 2mm at Z=0 (Pad_FC_Ledge)
    - Move the USB/switch cutouts into the front plate; add a battery-connector gap
    at CN1 (-Y side) through the ledge/wall
    - Backplate is now a thin CAP that clips around the front plate flush (lap relief
    + snap groove + closed-top skin); removed the old shelf/shell
    - Verified: all single watertight solids, FC<->BP overlap 0, PCB rests on ledge,
    ba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
    [WetGregCase-FrontCover.3mf, WetGregCase-Thumbpiece.3mf, WetGregCase.FCStd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]
2026-06-05 v13: notch the front-plate ledge around the 2 mount holes closest to the Y axis
    - Cut ledge notches at the two e-ink M2 mount holes nearest the Y axis
    (local x=2.4: (2.4,9.0) and (2.4,33.4)) so the ledge doesn't cover them;
    no through-hole, just the ledge relieved. Verified gaps at the holes, ledge
    intact between them; all parts single watertight solids.
    [WetGregCase.FCStd, WetGregCase_BackPlate.step, WetGregCase_FrontCover.step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]
2026-06-05 v14: rounded frame features (no corner overhang), patch battery wall hole, narrower front
    - frame_sketch now builds ROUNDED rectangles (corners follow the case fillet) so
    the ledge/tongue/bead no longer poke out past the rounded walls -> fixes the
    'rectangular overhang at the mate' and 'lip clipping out at the curved corners'
    - battery-connector gap now relieves only the ledge/interior, not the outer wall
    (cut starts at the wall inner) -> patched the side-wall hole
    - reduce -X extension (ext_xmin 3.0 -> 0.6): front plate = PCB width + walls
    (103.0mm, was 105.4)
    - verified: all single watertight solids, wall patched, ledge relieved, no overhang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
    [WetGregCase.FCStd, WetGregCase_BackPlate.step, WetGregCase_FrontCover.step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]
2026-06-05 v15: clamshell flip — front=screen lid (lip), backplate=deep curved cover (USB+Pico)
    - Seam moved to Z=0 (PCB plane). FRONT plate is now the screen lid (-11.4..0)
    with the PCB lip on top; BACKPLATE is the deep cover (0..7.5) that clips on and
    houses the USB-C + Pico, with the SAME r6 curved closed back as the front.
    - Moved USB-C + switch cutouts into the backplate; battery gap stays on the front
    (screen side), relieving only the ledge (not the outer wall).
    - All frame features (ledge/tongue/bead/relief/groove) are rounded -> no corner
    overhang at the mate or curved corners.
    - ext_xmin tuned to 1.2 (front = PCB + walls, 103.6mm); residual screen-corner
    overlap is the screen model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
    [WetGregCase.FCStd, WetGregCase_BackPlate.step, WetGregCase_FrontCover.step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]
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2026-06-06 v18: fix battery gap cutting through the front; keep the front floor solid
    - The front is CURVED at the battery gap (-Y edge), so a thin skin measured from
    the flat -11.4 plane wasn't actually solid and broke through.
    - Raise bat_floor 0.8 -> 2.4 so the gap floor sits ABOVE the whole 2mm front wall:
    the front skin is now fully solid/printable across the battery area (verified
    solid material below the gap at every sampled point, no cut-through). Cable space
    remains from ~-9.0 up (upper curve + rib).
    [WetGregCase.FCStd, WetGregCase_BackPlate.step, WetGregCase_FrontCover.step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]
2026-06-06 v19: fix PCB rib overhang at the curve — keep it on the straight wall + 45deg chamfer
    - The rib (at the straight wall position) detached where the front wall curves
    inward below Z=-5.4, leaving a hanging overhang.
    - Cap ledge_depth at 5.4 (= screen_top - front_curve) so the rib bottom stays on
    the STRAIGHT wall and remains joined to the case.
    - Chamfer the rib's inner-bottom edge to 45deg (Chamfer_FC_Ledge) so the underside
    is self-supporting (slopes from the wall up to the tip) -> prints cleanly.
    - Verified: rib joined to the wall, sloped underside, all single watertight solids.
    [WetGregCase.FCStd, WetGregCase_BackPlate.step, WetGregCase_FrontCover.step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]
2026-06-06 v20: PCB rib meets the front face and meshes with the curve (no chamfer)
    - Replace the chamfer with a full-depth rib: extend ledge_depth to 9.4
    (screen_top - wall) so the rib runs down to the front floor and MERGES with the
    curved wall (below the curve the straight rib outer falls inside the inward-
    curving wall -> meshes, no gap, no overhang, no poke-through).
    - Add a screen-clearance pocket so the rib clears the screen on the -X edge;
    FC<->assembly overlap dropped 8.37 -> 1.17 mm^3.
    - Verified: -Y rib solid Z0..-9.2 (meets front), single watertight solid.
    [WetGregCase.FCStd, WetGregCase_BackPlate.step, WetGregCase_FrontCover.step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]
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2026-06-06 v22: real snap-fit closure (discrete snap beads inside the lap, no added thickness)
    - Replace the too-subtle continuous bead/groove (slip fit, no retention) with
    DISCRETE snap beads on the front tongue (2 per long wall + 1 per short) that
    protrude 0.55mm past the backplate relief wall; matching recesses capture them.
    - Deepen the lap to 3mm so the thin (1mm) tongue is a flexible cantilever -> the
    beads flex ~0.35mm and click into the recesses; relief wall stays solid between
    recesses for retention. Beads have a top lead-in chamfer for assembly.
    - Entirely inside the lap: no external features, no added thickness (height still
    22.9mm). Verified: beads protrude, recesses capture, seat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
    [WetGregCase.FCStd, WetGregCase_BackPlate.step, WetGregCase_FrontCover.step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]
2026-06-06 v23: move +X snaps to flank the USB-C port (keep the port hole intact)
    - The +X short-wall snap was at y=21, right on the USB-C port -> it clipped the
    opening. Replace it with TWO snap clips flanking the port (centred clear of the
    usb_w opening + margin), so the USB-C hole stays open.
    - Narrow snap_w 8 -> 6 so the flanking clips fit beside the port.
    - Verified: USB opening open, 2 flank recesses present, all single watertight solids.
    [WetGregCase.FCStd, WetGregCase_BackPlate.step, WetGregCase_FrontCover.step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]
2026-06-06 v24: fix snap recess depth (don't cut the back curve) + -X snap missing the extended wall
    - Recesses were proj+clr deep, leaving ~0.1mm outer skin -> cut through the curved
    back wall and turned the -X recess into an open hole (no joinage). Now depth =
    (bead_proj - lap_fit) + 0.1 (just enough for the bead to seat), leaving ~0.5mm
    solid outer skin = proper blind catches that don't break the curve.
    - The -X bead/recess ignored ext_xmin, so on the extended -X wall the bead floated
    off the tongue and the recess missed the wall -> add EXT to the -X positions
    (bead + recess + lead-in). Verified: -X bead on tongue, recess in wall w/ skin.
    - Ease bead_proj 0.55 -> 0.40 (interference 0.2) so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
    [WetGregCase-BackPlate.3mf, WetGregCase-FrontCover.3mf, WetGregCase.FCStd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]
2026-06-06 v25: add USB-C clearance gap in the front plate +X tongue (connector settles in)
    - The USB-C connector dips to Z=0.67 and overhangs the +X board edge, colliding
    with the front plate's +X tongue. Pocket a gap in that tongue at the port
    (between the two flanking snaps) so the connector settles into the front plate.
    - Verified: +X tongue open at the USB, flanking snaps intact, connector clears
    (FC<->assembly overlap 0.70mm^3); all single watertight solids.
    [WetGregCase-BackPlate.3mf, WetGregCase-FrontCover.3mf, WetGregCase.FCStd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]
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2026-06-06 v27: +1mm front thickness, shave window long edges -4mm, auto-3MF, changelog
    - screen_top 11.4 -> 12.4 (front cover +1mm); ledge_depth tracks to 10.4
    - shave 2mm off each end of the window's long (X) edges: win_x 10.6..65.6 ->
    12.6..63.6 (long edges 4mm shorter)
    - macro now auto-exports print-ready 3MF meshes for all 3 parts on each run
    - add CHANGELOG.md (full revision history v1..v27 + current key dims); sync
    DESIGN-PROGRESSION numbers; commit regenerated FCStd/STEP/3MF + manual 3MF exports
    - overall height 18.9 -> 19.9mm; all parts single watertight solids
    [WetGregCase-BackPlate.3mf, WetGregCase-FrontCover.3mf, WetGregCase-Thumbpiece.3mf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]
2026-06-06 v28: trim +X end 1mm past the USB-C + power-switch clearance gap in front tongue
    - Trim the +X end by trim_xmax=1.0 (slab cut both parts to ~99.1, just past the
    USB-C at 98.6). The two USB-flanking +X snaps don't fit in the trimmed zone, so
    drop them (closure now 4 long-wall beads + 1 -X = 5). USB opening still clears.
    - Cut a power-switch clearance gap in the front -Y tongue (Cut_FC_Switch) so it
    no longer hits the switch actuator when mated (FC<->assembly 0.7->0.13).
    - Verified: +X material removed at x>=99.2 both parts; switch gap open; seated
    FC<->BP overlap 0; all single watertight solids. Update CHANGELOG (v28).
    - Regenerated FCStd/STEP/3MF.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
    [WetGregCase-BackPlate.3mf, WetGregCase-FrontCover.3mf, WetGregCase-Thumbpiece.3mf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]
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2026-06-06 v29: shorten via board_w (96.8), not a slab cut — restore +X corner curves
    The v28 +X slab trim flat-chopped the rounded corner and edge fillet ('melted'
    look). Undo it: drop Cut_FC_Xtrim/Cut_BP_Xtrim and the trim_xmax param, and
    shorten the case 1 mm by reducing board_w 97.8 -> 96.8 (the real board is 1 mm
    shorter than the KiCad nominal). The whole case now regenerates 1 mm shorter
    (+X edge 100.1 -> 99.1) with every fillet/curve intact. Restore the 2 +X snaps
    flanking the USB-C now that the +X wall is whole again (closure = 7 beads).
    Verified: all 3 parts single/valid/closed; +X wall solid, corner rounded, USB
    port open, seated FC<->BP overlap 0. Regenerated FCStd/STEP/3MF. Docs synced.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
    [WetGregCase-BackPlate.3mf, WetGregCase-FrontCover.3mf, WetGregCase-Thumbpiece.3mf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]
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2026-06-07 v31: firmer clasp — continuous tongue + thicker bead/walls + deeper USB opening
    - Drop the front-tongue relief cuts at the USB-C and switch (Cut_FC_USB,
    Cut_FC_Switch) so the snap bead runs unbroken around the whole lap.
    - bead_proj 0.4 -> 0.8 (+0.4) for a firmer click (interference 0.2 -> 0.6).
    - wall 2.0 -> 2.4 (+0.4 outer shell all around), corner_r 7.3 -> 7.7 and
    ledge_depth 10.4 -> 10.0 to track the wall. The thicker wall keeps a ~0.5 mm
    solid skin behind the deeper recess (was ~0.1 mm) so the back wall isn't cut
    through, and the halves still mate flush.
    - usb_z1 5.0 -> 5.2 (+0.2 USB-C opening depth).
    Verified: 3 single/valid/closed solids; seated FC<->BP overlap 0; walls +0.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
    [WetGregCase-BackPlate.3mf, WetGregCase-FrontCover.3mf, WetGregCase-Thumbpiece.3mf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]
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2026-06-07 v37: extend USB-C cut inboard to remove the top cap's inward lean
    The cap's r6 back-edge fillet curves the material toward -X near the top, so it
    sat at x~91-93.5 over the USB window - inboard of the cut start (96.1), so the
    slot missed it and the curve still overhung. Start Cut_BP_USB back_curve (6mm)
    further inboard (x0 = BW+C-back_curve-1.0) and lengthen to match. Now the whole
    curved corner over the USB window is removed up to the back face. Verified: cap
    cleared at x=92.5..96 across z=5..8.3 in the USB window; cap intact off-window
    (y=10,33) and Pico ceiling untouched; BackPlate single/valid/closed.
    Regenerated FCStd/STEP/3MF.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
    [WetGregCase-BackPlate.3mf, WetGregCase-FrontCover.3mf, WetGregCase-Thumbpiece.3mf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]
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2026-06-07 v39: front-cover USB lip (covers bead/seam, flush) + back depth +0.4mm
    - Add Lip_FC_USB to the front cover: an outer lip at the USB-C notch (x = tongue
    outer..OX1, Y = usb_w-2*lap_fit, Z = 0..usb_lip_h=2.1) that fills the LOWER part
    of the backplate's USB cutout flush with the outer +X surface, covering the
    exposed bead/seam. New param usb_lip_h (bound via setExpression). Port mouth
    stays open above the lip; seated FC<->BP overlap stays 0 (no collision).
    - back_above 8.5 -> 8.9 (+0.4) so the Pico doesn't bottom out on the shell and
    block the snap. Overall height 20.9 -> 21.3.
    Verified: 3 single/valid/closed solids; lip flush; USB open above lip.
    Co-Auth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
    [WetGregCase-BackPlate.3mf, WetGregCase-FrontCover.3mf, WetGregCase-Thumbpiece.3mf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]
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2026-06-08 v42: calibrate reference assembly to reality (screen + USB-C fit)
    - Screen: stop shoving it -1.36mm onto the case front floor; keep it at its
    authoritative STEP position (screen_cal=0). Real screen front = -8.64, ~1.36mm
    behind the window frame (a real air gap). The exact artificial shift was 1.36mm.
    - Extend the rib's screen-clearance pocket to the real screen back (new param
    screen_back=-5.30) so the rib no longer collides with the (now-correctly-placed)
    screen. Screen-vs-rib intersection 33 -> 0.10.
    - USB-C was colliding with the front cover on the model: lower the outer lip below
    the connector (usb_lip_h 2.1 -> 0.5, connector bottom is 0.67) and re-add a
    narrow tongue relief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
    [WetGregCase-BackPlate.3mf, WetGregCase-FrontCover.3mf, WetGregCase-Thumbpiece.3mf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]
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2026-06-08 v44: bring -X side in 0.9mm to the screen edge + restore USB lip to meet connector
    - ext_xmin 1.2 -> 0.3: -X wall cavity inner -1.5 -> -0.6, clearing the screen
    overhang (-0.394, the -X-most feature) by 0.2mm wiggle. -X outer -3.9 -> -3.0.
    Clamp the screen-clearance pocket -X to the cavity inner so it doesn't notch the
    now-thin wall.
    - usb_lip_h 0.5 -> 0.67 so the front-cover USB lip meets the connector bottom.
    Verified: -X wall solid, screen clears (overlap 0.134), all parts single/valid/
    closed, seated FC^BP 0. Regenerated FCStd/STEP/3MF.
    [WetGregCase-BackPlate.3mf, WetGregCase-FrontCover.3mf, WetGregCase-Thumbpiece.3mf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]
2026-06-08 v45: lower the snap bead so its top is flush with the PCB top
    board_t 1.6 -> 1.47 (real, from STEP); bead_z = board_t - bead_h so the bead top
    sits at the PCB top (1.47) instead of 2.1. Beads + recesses move together
    (seated FC^BP overlap stays 0). All parts single/valid/closed.
    Note: kept the minimal USB tongue relief. 'Raise the board to clear the
    connector' + 'bead flush with PCB top' are geometrically incompatible (the USB-C
    connector bottom is at 0.67, below the PCB top 1.47) and raising the board would
    push the Pico into the back cover, requiring a thicker back. Regenerated outputs.
    [WetGregCase-BackPlate.3mf, WetGregCase-FrontCover.3mf, WetGregCase-Thumbpiece.3mf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]
2026-06-08 v46: slide-switch (MSK12C02) slider v1 + enlarged slot
    - Replace the simple switch cut with a slider WINDOW in the -Y backplate wall
    sized for a slider neck + travel (new sw_*/sld_* params; MSK12C02 8x2.8x1.4).
    - Add build_switch_slider(): a printed SwitchSlider part (thumb tab outside +
    neck through the slot + a grip pocket that straddles the actuator knob), exported
    as STEP + 3MF. Valid single solid; rides the slot with sld_fit clearance
    (slider^backplate=0); neck reaches the switch face.
    - Save MSK12C02 to project memory.
    v1 caveats (documented): the actuator knob width/protrusion/travel aren't in the
    LCSC listing (assumed 1.2/0.6/1.5mm) and the model's switch has no separate kno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
    [WetGregCase-BackPlate.3mf, WetGregCase-FrontCover.3mf, WetGregCase-SwitchSlider.3mf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]
2026-06-08 v47: raise the board so PCB top is flush with the bead top (board_rest_z)
    Reverse the v45 approach: instead of lowering the bead to the board, RAISE the
    board to the bead. New board_rest_z=0.63 (= bead_top - board_t); bead restored to
    the lap centre (top 2.1). Effects:
    - PCB top now flush with the bead top (board Z 0.63..2.10, verified).
    - USB-C + switch lift into the backplate wall -> accessible; front USB lip grows
    (usb_lip_h 0.67 -> 1.3, = connector bottom + board_rest_z).
    - Front cover thinner (screen_top 11.04 -> 10.41; overall 19.94 -> 19.31). Screen
    still meets the window (front -8.006 vs inner -8.01). Pico still clears the back
    ceiling (5.89 < 6.5) so the back cover is unchange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
    [WetGregCase-BackPlate.3mf, WetGregCase-FrontCover.3mf, WetGregCase-SwitchSlider.3mf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]
2026-06-08 v48: board rests ON the bead -> remove USB relief, lip meets bead top
    board_rest_z 0.63 -> 2.13: the board bottom sits ~at the bead top (2.10), so it
    rests ON the bead/shelf and the USB-C connector base (2.80) clears the tongue top
    (2.8). Effects:
    - Remove Cut_FC_USB entirely: USB connector ^ FrontCover = 0 (verified), so the
    bead/tongue fully connect under the connector with no cutout.
    - Lip meets the bead top (usb_lip_h -> 2.10).
    - Pico rises to ~7.39; deepen back_above 8.9 -> 10.2 so it clears (0.41mm margin,
    Pico not in collision list). usb_z1 -> 7.2 for the raised connector (top ~7.0).
    - screen_top -> 8.91 keeps the screen at the window (front -6.506 vs inner -6.51).
    - Overall 19.31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
    [WetGregCase-BackPlate.3mf, WetGregCase-FrontCover.3mf, WetGregCase-SwitchSlider.3mf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]
2026-06-08 v49: board exactly flush with bead + restore USB-C/Pico in the assembly
    Fix two v48 regressions:
    - board_rest_z 2.13 -> 2.10 (= bead top): board bottom now exactly flush with the
    bead top (verified 2.100). screen_top -> 8.94 to keep the screen at the window.
    - Header-strip filter in import_assembly used a fixed ZMax>6.0, which (after the
    board raise) was deleting the Pico (top ~7.4) and USB-C (~7.0) as if they were
    header pins. Raise both thresholds by board_rest_z; assembly back to 286 solids,
    USB-C + Pico restored.
    Verified: USB-C ^ FrontCover 0, seated FC^BP 0, Pico clears (0.44mm), all parts
    single/valid/closed.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
    [WetGregCase-BackPlate.3mf, WetGregCase-FrontCover.3mf, WetGregCase-SwitchSlider.3mf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]
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
